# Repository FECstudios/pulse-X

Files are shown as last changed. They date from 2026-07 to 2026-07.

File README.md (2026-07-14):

# Pulse-X: Crowd Cheering Tool

Pulse-X is a portable battery powered cylindrical speaker engineered for high-noise outdoor environments, such as sports stadiums and open-air events. Works with wifi, bluetooth or locally with a sd card. Made this project to be used in VEX and FIRST competitions.

## Renders
Pulse-X Hardware View

## Hardware Schematics
circuit_image (6)

## Images


Demo Video: https://www.youtube.com/shorts/XgMtZgEX2DE
---
# Technical Overview

Pulse-X is powered by an ESP32-S3-WROOM-1. The ESP32 handles the web interface, audio streaming, and the OLED display at the same time. Audio is sent over I2S to a PCM5102A DAC OR with VHM-314, which provides much better sound quality than the built-in DAC found on many microcontrollers.

## Features

- Joins a public wifi, allowing devices to connect to it with BubbleUPnP or MediaMonkey
- Uses a PCM5102A I2S DAC for clean digital audio output.
- Uses a VHM-314 instead of built in bluetooth for smoother audio.
- 128×64 OLED display showing the current mode, volume level, playback status, and scrolling track names.
- Six physical buttons for volume control, play/pause, previous track, next track, and mode switching.
- Powered by a 3-cell Li-ion battery pack with a 3S BMS for battery protection and a buck converter to provide power to the components.
- Bluetooth, wi-fi AND sd card connectivity.
- On/Off and connection sounds
- Bluetooth module can be integrated as shown in schematics but its optional

---

# Hardware Connections

## Main Components

- ESP32-S3 N16R8 Development Board
- 1.3" SSD1306 OLED Display (I2C)
- PCM5102A I2S DAC Audio Decoder Module
- PAM8610 Stereo Audio Amplifier
- VHM-314 Bluetooth 5.0 Audio Receiver Module
- Micro SD Card Reader Module
- 2 × 4 Ω 5 W Speakers (66 × 66 mm)
- 7 × 6 × 6 mm Tactile Push Buttons (4.3 mm Height)
- MP1584 3A Step-Down (Buck) Voltage Regulator
- 3 × LG HG2 3000 mAh 3.7 V 20A 18650 Li-ion Batteries
- 3S 20A Battery Management System (BMS)
- 3S Li-ion/LiPo 12.6 V 2A Charging Module
- KCD1-101 3-Pin Mini Power Switch
- VHM-314 Bluetooth module   // OPTIONAL

| NAME | QUANTITY | PRICE PER UNIT (TL) | TOTAL (TL) | SELLER | SHIPPING (TL) | LINK |
|---|---:|---:|---:|---|---:|---|
| LG HG2 3000 mAh 3.7V 20A 18650 Li-ion Battery | 3 | 299.00 | 897.00 | Trendyol | 59.99 | https://www.trendyol.com/lg/hg2-3000-mah-3-7-v-20a-18650-li-ion-sarj-edilebilir-pil-p-142219925 |
| 1.3" SSD1306 OLED Screen | 1 | 227.31 | 227.31 | Direnç.net | 144.00 | https://www.direnc.net/13-inc-4-pin-oled-ekran-modulu-ssd1306-i2c-beyaz |
| ESP32-S3 N16R8 | 1 | 568.26 | 568.26 | Direnç.net | 0.00 | ESP32 S3 N16R8 WiFi Bluetooth Board |
| 6x6 4.3mm Tact Button | 7 | 1.48 | 10.36 | Direnç.net | 0.00 | https://www.direnc.net/6x6-42mm-tach-buton-4-bacak-en |
| Speaker 4Ω 5W 66×66mm | 2 | 86.40 | 172.80 | Motorobit | 137.00 | http://motorobit.com/hoparlor-4-ohm-4%CE%A9-5w-66x66mm |
| MP1584 Step-Down Voltage Regulator 3A | 1 | 50.22 | 50.22 | Robo90 | 0.00 | https://www.robo90.com/mp1584-dusurucu-voltaj-regulatoru-buck-3a |
| Micro SD Card Reader | 1 | 30.69 | 30.69 | Robo90 | 0.00 | https://www.robo90.com/micro-sd-kart-okuyucu-modulu-arduino-uyumlu |
| PAM8610 Sound Booster | 1 | 83.70 | 83.70 | Robo90 | 0.00 | https://www.robo90.com/pam8610-mini-dijital-ses-yukseltici |
| PCM5102A I2S DAC Audio Decoder Module | 1 | 50.22 | 50.22 | Robo90 | 0.00 | https://www.robo90.com/pcm5102a-i2s-dac-dekoder-modul |
| 3S 20A BMS | 1 | 50.40 | 50.40 | Robolink Market | 0.00 | https://www.robolinkmarket.com/3s-20a-bms-batarya-yonetim-ve-koruma-modulu |
| 3S Li-ion and LiPo Battery Charging Module 12.6V 2A | 1 | 52.20 | 52.20 | Robolink Market | 0.00 | https://www.robolinkmarket.com/3s-lion-ve-lipo-sarj-modulu |
| KCD1-101 3-Pin Mini | 1 | 5.18 | 5.18 | Motorobit | 0.00 | https://www.motorobit.com/kcd11-3-pin-mini-on-off-anahtar-siyah |
| VHM-314 | 1 | 111.60 | 111.60 | Robo90 | 0.00 | https://www.robo90.com/bluetooth-50-mikrofonlu-mp3-stereo-muzik-modulu-ses-alicisi |
| **Components Total** |  |  | **2,310.94 TL** |  |  |  |
| **Shipping Total** |  |  | **340.99 TL** |  |  |  |
| **Grand Total** |  |  | **2,651.93 TL** |  |  |  |

---

# Software

Pulse-X can be programmed using either the Arduino IDE or ESP-IDF.
Preprogrammed versions are available at firmware/bluetooth.ino firmware/onlySD.ino firmware/wifinsd.ino 

---

# Steps To Replicate

1. 3d print all of the files given at folder 3dprintfiles with your preferred slicer.
2. Solder and connect all of the components as shown in schematics
3. Flash the firmware to the esp32
4. Charge the batteries
5. Download your sound effects and preferred musics to the sd card
6. Connect all of the 3d printed pieces together
7. Connect to the device

# AI usage
AI was used to help write the firmware for this project. AI was partly used in part selection and troubleshooting.

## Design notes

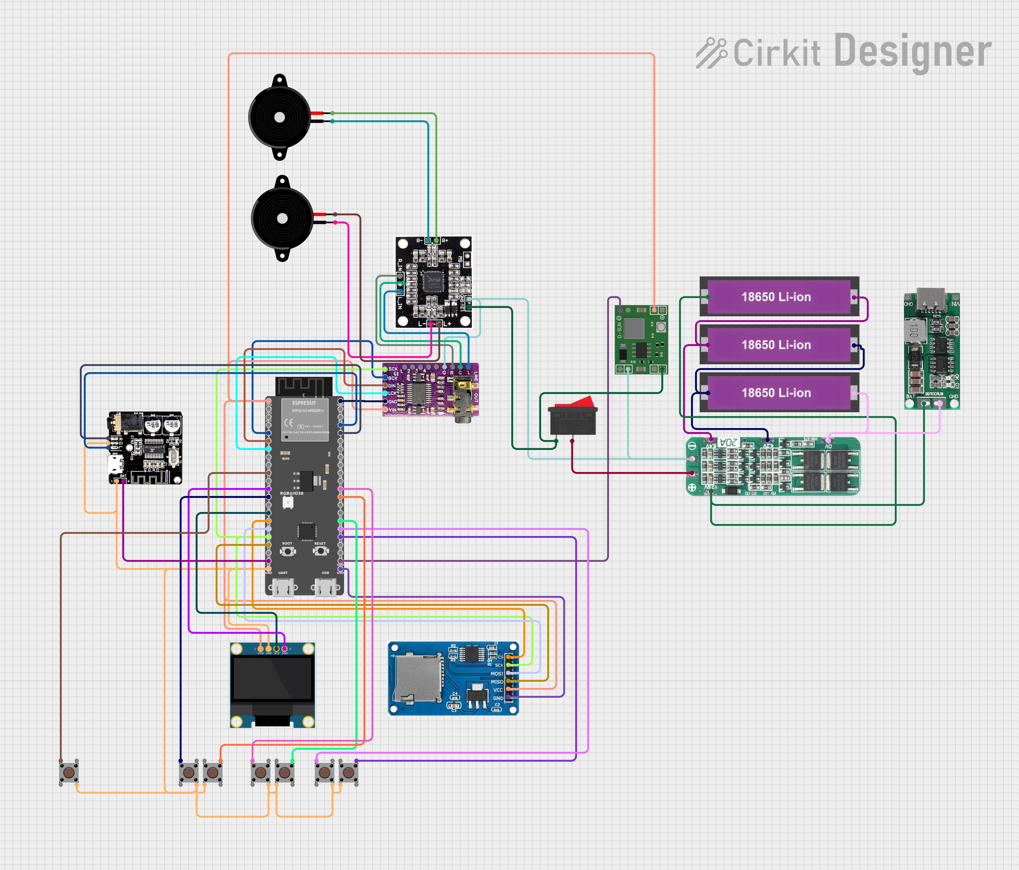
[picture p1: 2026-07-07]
circuitimage.png

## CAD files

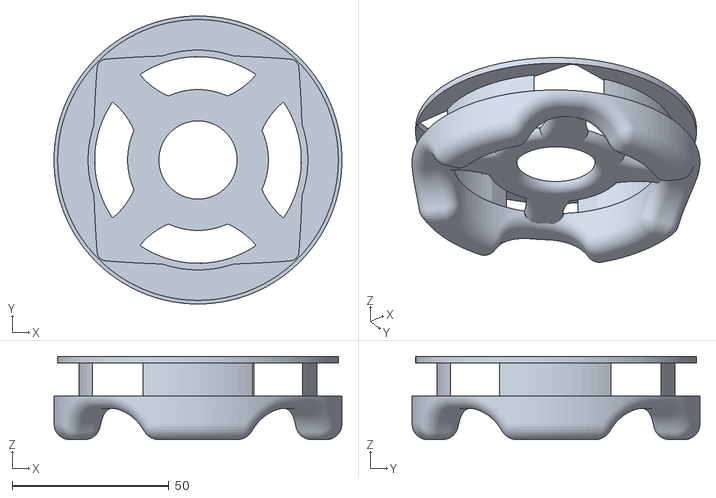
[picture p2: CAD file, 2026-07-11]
3dprintfiles/BOTTOM.stl
92.0 x 92.0 x 26.6

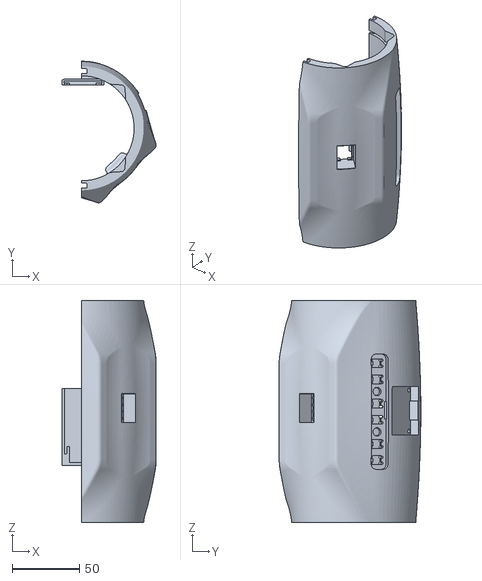
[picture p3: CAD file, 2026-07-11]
3dprintfiles/right.stl
70.2 x 105.3 x 165.0

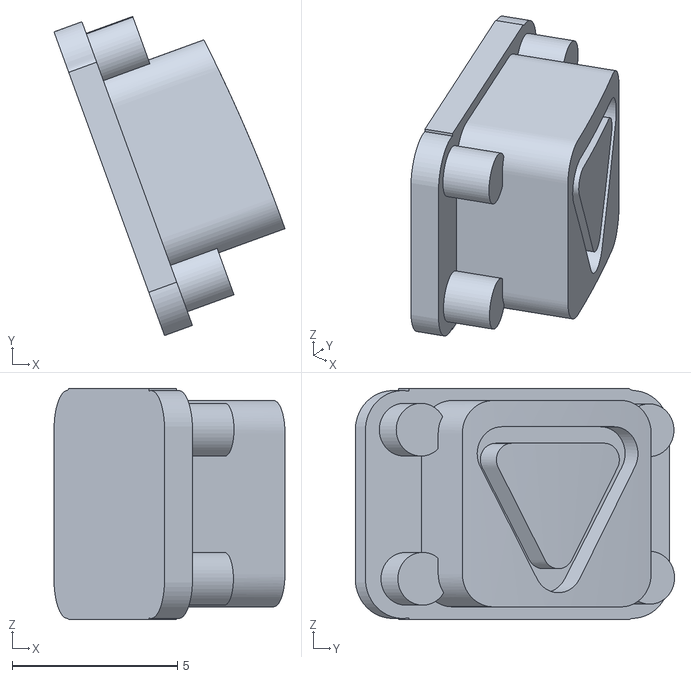
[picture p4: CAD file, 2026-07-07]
3dprintfiles/button4.stl
7.00 x 9.67 x 7.01

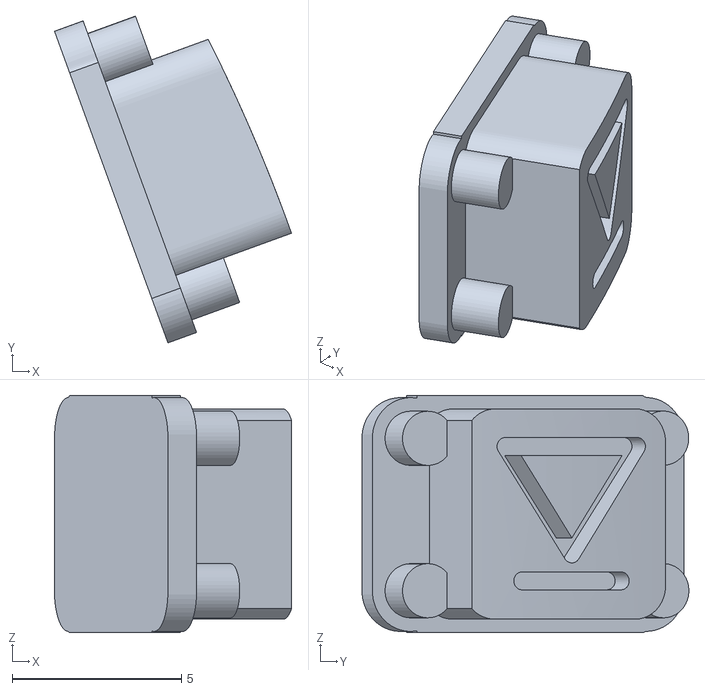
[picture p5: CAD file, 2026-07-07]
3dprintfiles/button1.stl
7.00 x 9.65 x 7.01

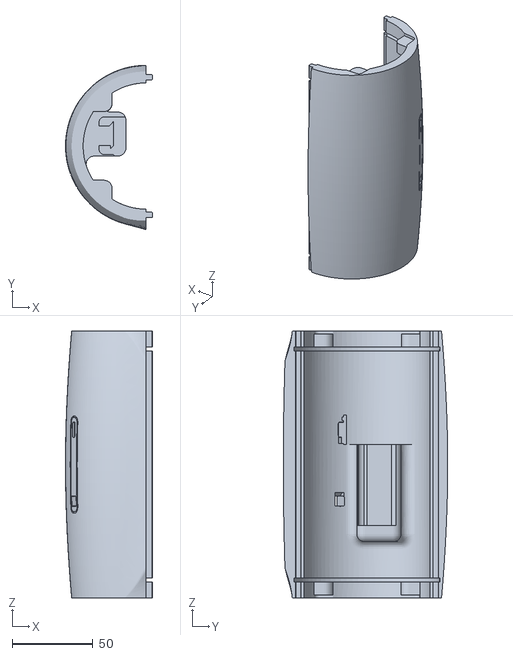
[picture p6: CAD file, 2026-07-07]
3dprintfiles/left.stl
53.8 x 101.6 x 165.0

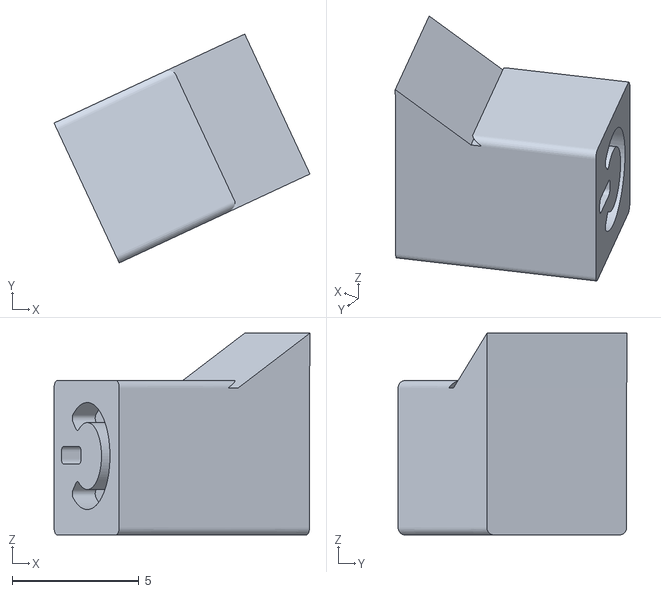
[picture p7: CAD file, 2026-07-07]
3dprintfiles/ONOFF.stl
10.1 x 9.04 x 7.98

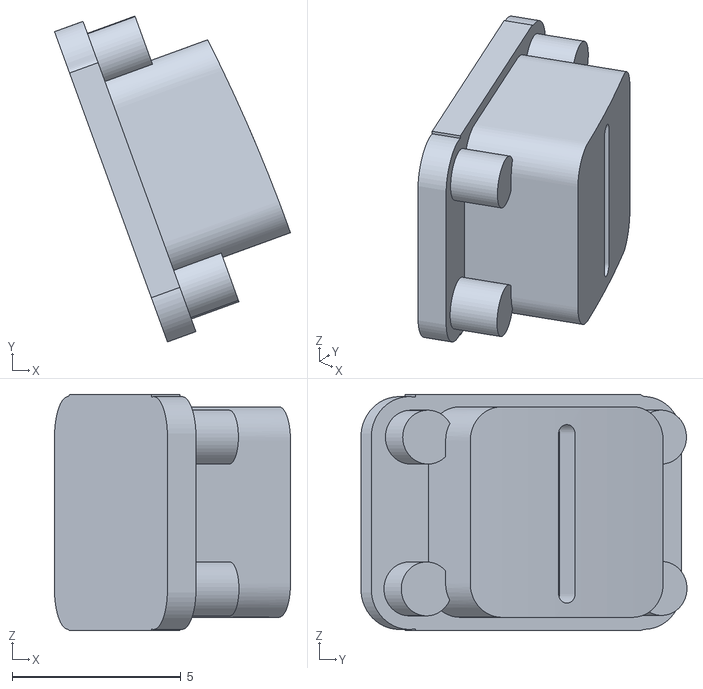
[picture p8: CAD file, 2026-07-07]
3dprintfiles/button6.stl
7.00 x 9.66 x 7.01

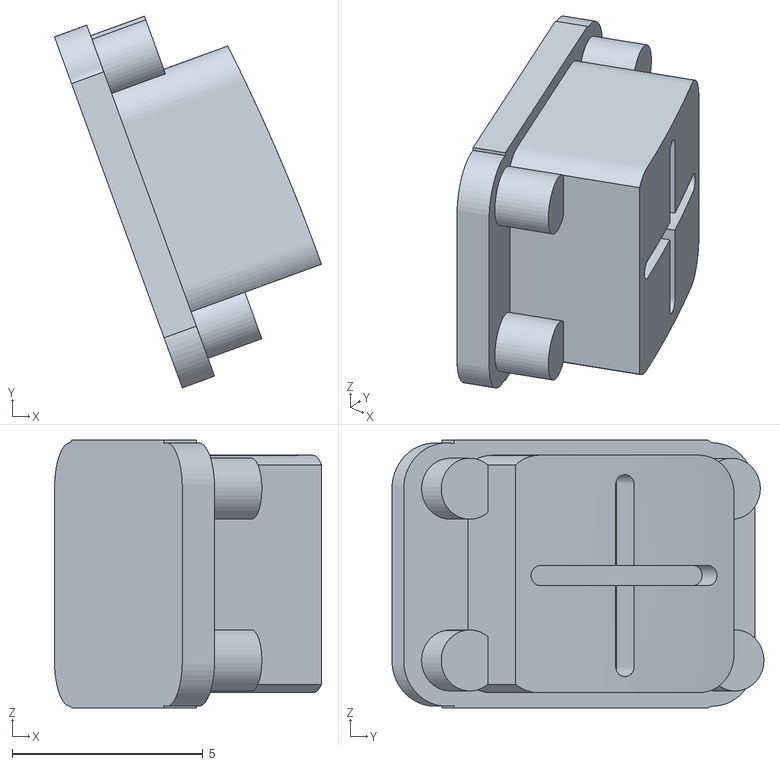
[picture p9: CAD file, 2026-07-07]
3dprintfiles/button5.stl
7.00 x 9.74 x 7.01

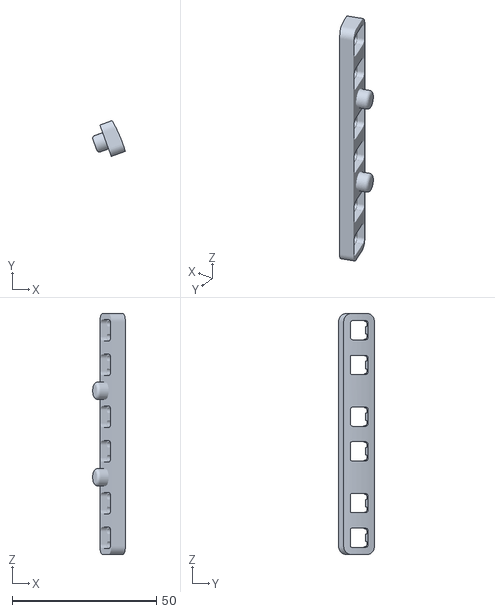
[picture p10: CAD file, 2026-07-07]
3dprintfiles/butonholders.stl
11.4 x 12.4 x 83.6

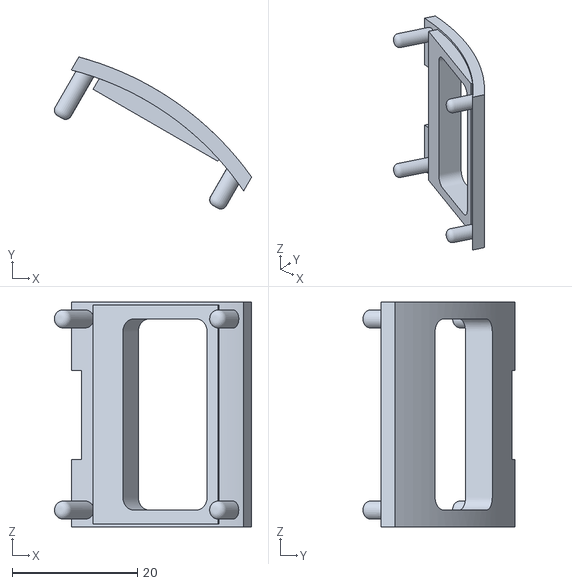
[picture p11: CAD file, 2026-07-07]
3dprintfiles/screencover.stl
31.5 x 24.3 x 35.9

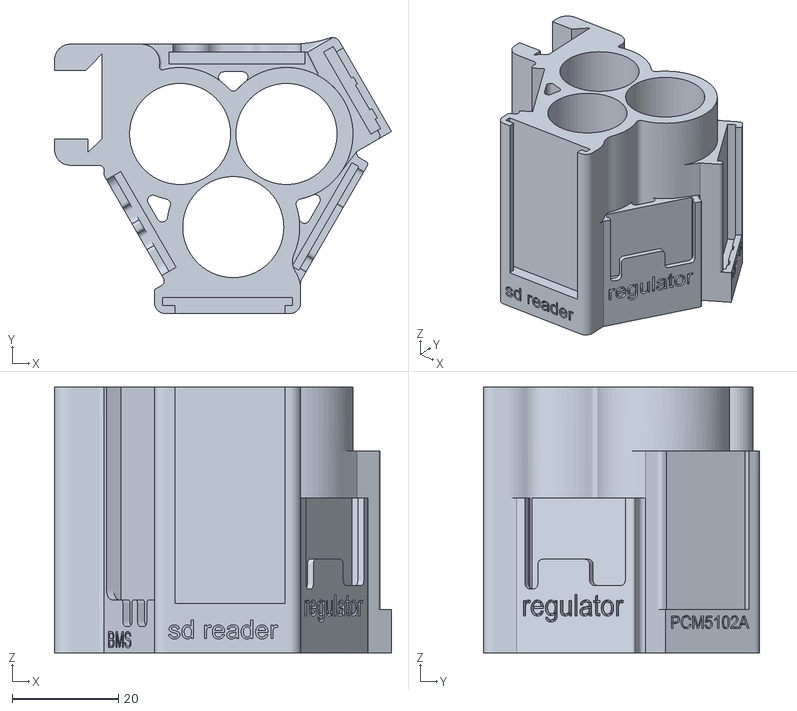
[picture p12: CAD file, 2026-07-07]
3dprintfiles/batteryholders.stl
63.3 x 51.9 x 50.0

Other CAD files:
3dprintfiles/top (4).stl
3dprintfiles/button2.stl
3dprintfiles/button3.stl

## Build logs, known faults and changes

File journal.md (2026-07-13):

title: PULSE-X
author: Kuzey (@craftfec) and Derin (@D_R1N)
description: Pulse-X is a portable battery powered cylindrical speaker engineered for high-noise outdoor environments, such as sports stadiums and open-air events.
created_at: "2026-06-26"

# June 26th: Started the project!
Author: craftfec

Today we started a new project it will be a bluetooth and wifi speaker made to cheer up the crowd at robotics matches at least that is what we want to build. We started with making a parts list and started making the cad files



**Total time spent: 2h 2m**
Recordings:
https://lapse.hackclub.com/timelapse/x79JwHw80_DK
https://lapse.hackclub.com/timelapse/8_gKt_B3zJ5e

# June 26th: Started the project!
Author: D_R1N

On our new project i started to select the parts we will use and worked on the schematics using the circit designer tool



**Total time spent: 2h 12m 26s**
Recordings:
https://lapse.hackclub.com/timelapse/CJvV61tmcs52
https://lapse.hackclub.com/timelapse/yrJAcUiZQl9d

# June 28th: Started CAD designing on fusion
Author: craftfec

Today i started the cad design by firstly designing the battery holders and also added slots for 3 more components with the batteries to reduce the ammount of wires used inside the build. Also tried to get a good cad model for the specific speakers we ordered but unfortunately had no luck



**Total time spent: 2h 16m 5s**
Recordings:
https://lapse.hackclub.com/timelapse/_Vc3Hfp5rxpG

# June 29th: More cad designed and parts ordered
Author: craftfec

Today i continued with the battery holder design, added slots for 2 more components and made the design look aesthetically pleasing. Also ordered the parts left after my friend bought the first half



**Total time spent: 1h**
Recordings:
https://lapse.hackclub.com/timelapse/xlZ42-g_Gx9J

# July 2nd: Finished the battery holders and started working on the case
Author: craftfec

Today we met up at my friends house, added sd card reader and printed the battery holders after that i started working on the outside of the speaker adding spikes on left and right sides for placing the device at 90 degrees and added feet for sideways placement



**Total time spent: 4h 2m**
Recordings:
https://lapse.hackclub.com/timelapse/tpy7AgIwUa08

# July 2nd: Printing the battery holders and soldering the batteries
Author: D_R1N

Today we met up at my house and printed the battery holders, after that i started to solder the batteries but couldnt without proffesional help. After trying for a while i gave up thinking the batteries could have been damaged from the heat.



**Total time spent: 2h 47m 14s**
Recordings:
https://lapse.hackclub.com/timelapse/5dx7Ywu7mEY0

# July 3rd: Trip to the factories
Author: D_R1N

Today we went on a trip to get the batteries professionaly made. After we got them done i continued with the soldering finishing up the bms, regulator and the charger. After that we could succesfully charge the 18650 batteries



**Total time spent: 3h 04m 48s**
Recordings:
https://lapse.hackclub.com/timelapse/M9-L9wLn_zZr

# July 3rd: On Off buttons
Author: craftfec

After coming back from our trip we realized that we need to add some sort of phsical switch to cut the electric or else the esp32 and the speaker would be constantly active and draining our batteries so i added a on off switch and hit in on the bottom of the model
Esp32 deep sleep mode button design:


**Total time spent: 1h 56m 41s**
Recordings:
https://lapse.hackclub.com/timelapse/lTfWhkKVHinp

# July 4th: Media control button designs
Author: craftfec

Today i added the button holders and all the buttons in a innovative style so that the buttons dont fall out or dont fall inside the case




**Total time spent: 2h 53m 1s**
Recordings:
https://lapse.hackclub.com/timelapse/X4p78sh8nN9x

# July 4th: SVG, sound effects and more solder
Author: D_R1N

Today i tried to find some good svg designs, audio effects to send to my friend who is doing the cad design. Also worked on some ui code on the oled screen. In the afternoon i acquired the parts from my friend and started working on the solder




**Total time spent: 2h 42m 23s**
Recordings:
https://lapse.hackclub.com/timelapse/QX8U-kUTgIU8
https://lapse.hackclub.com/timelapse/zpm87LCeGYsF
https://lapse.hackclub.com/timelapse/9LhlHynIek39

# July 5th: Fixing my mistakes with the solder
Author: D_R1N

Today i learned the sad news that we needed to connect the batteries better with the BMS so i worked on doing that and also fixed the regulator connections


**Total time spent: 1h 26m**
Recordings:
https://lapse.hackclub.com/timelapse/i443_Us5i-Yl

# July 5th: Speaker protector and schematics
Author: craftfec

Today i added a speaker protector to our top and bottom parts and sent the models to print to my friend Derin and started working on the schematics on circitdesigner




**Total time spent: 2h 5m**
Recordings:
https://lapse.hackclub.com/timelapse/fUiaW7e-g2Ig
https://lapse.hackclub.com/timelapse/-oq5R-IBSlbL

# July 6th: BLE issues
Author: craftfec

Today i finished up the schematics design and realized the bluetooth on the esp32 s3 does not have regular bluetooth but only has Bluetooth low energy so we added a new component VHM-314 to our schematics and to our bom.
Also wrote all of the journals we were dreading to write.




**Total time spent: 3h**
Recordings:
https://lapse.hackclub.com/timelapse/h-_9Gzua42wM
https://lapse.hackclub.com/timelapse/YINomfWPwFnc

# July 6th: Right side of the case
Author: D_R1N

Today i printed the right side of the case design and continued my work on the left side integrating the buttons, the on off switch the screen and more



**Total time spent: 2h 51m 9s**
Recordings:
https://lapse.hackclub.com/timelapse/utEOT1DLX6nZ

# July 7th: Issues with the Esp32 S3
Author: D_R1N

Today i had some issues with flashing the test firmwares to the esp32 s3 since i couldnt meet up with kuzey because of the NATO Ankara Summit i decided to use my cheap and probably cloned esp32D and still could not get the oled display to work with both of my esp32's :(




**Total time spent: 4h 35m 01s**
Recordings:
https://lapse.hackclub.com/timelapse/nuqc9frhJh3B

# July 7th: Issues with the Esp32 S3 and firmware
Author: craftfec

Today i countinued my day by writing the firmware but recieved the sad news that my friend couldnt flash anything on the chip i previously tested and managed to work then continued by trying to help him but achieved no success with the esp32 s3 AND the oled screen hopefully we will meet sometime and get those fixed


**Total time spent: 6h 20s**
Recordings:
https://lapse.hackclub.com/timelapse/LaqP55hy5ArD
https://lapse.hackclub.com/timelapse/Q2pDoU28dboI

# July 8th: Issues with speakers
Author: D_R1N

Today i countinued with soldering of the speakers but i couldnt get them to work with my Esp32D in the end the chip started overheating


**Total time spent: 2h 16m**
Recordings:
https://lapse.hackclub.com/timelapse/n-Ss9dm3OcC4

# July 9th: The big meetup and solder
Author: D_R1N

Today we finally met up in my friends place and he finally got his hands on the project. We started the work with getting the esp32d out since it was short circuting. Then we fixed the oled screen and soldered all of the pieces together


**Total time spent: 1h 59m 1s**
Recordings:
https://lapse.hackclub.com/timelapse/Yu9Xosdbv95M

# July 9th: The big meetup and code
Author: craftfec

Today we finally met up in my place and i finally got my hands on the project. After finishing up all of the wiring we had some issues with the code since i was uploading the code but the device did not recieve it or kept rebooting at the end the issue was fixed by increasing the mb and fixing psram settings from the arduino ide



**Total time spent: 4h**
Recordings:
https://lapse.hackclub.com/timelapse/Iv2Pfilxi044

# July 11th: The 2nd big meetup and wifi connectivity
Author: craftfec

Today we met up again and worked a lot on getting the wifi functionality with UPNP and i fixed the cad models of the parts that showed issues in the model


**Total time spent: 5h 32m 10s**
Recordings:
https://lapse.hackclub.com/timelapse/v2fOV9HvRw3P

# July 12th: The end.
Author: craftfec

Today was a beautiful morning since we succesfully finished the demo of the project and filmed the demo video, uploaded the finally done code to github. Downloaded some of the offline songs we wanted.



**Total time spent: 2h 30m 2s**
Recordings:
https://lapse.hackclub.com/timelapse/Yv39VQiENtMH

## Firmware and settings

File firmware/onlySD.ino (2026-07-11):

#include <Wire.h>
#include <Adafruit_GFX.h>
#include <Adafruit_SSD1306.h>
#include <SPI.h>
#include <SD.h>
#include <Audio.h>

// Pin Definitions
#define SDA_PIN     8
#define SCL_PIN     9
#define SD_CS       10
#define SPI_MOSI    11
#define SPI_SCK     12
#define SPI_MISO    13
#define I2S_BCLK    5
#define I2S_LRC     7
#define I2S_DOUT    6
#define BTN_VOL_UP  3
#define BTN_VOL_DN  41
#define BTN_PLAY    40
#define BTN_PREV    47
#define BTN_NEXT    21

// Display Configurations
#define SCREEN_WIDTH  128
#define SCREEN_HEIGHT 64
#define OLED_RESET    -1
#define I2C_ADDRESS   0x3C

// Audio Configurations
#define MAX_TRACKS    100
#define MAX_VOLUME    21
#define DEBOUNCE_MS   250
#define SCROLL_MS     40

// Global Objects
Adafruit_SSD1306 display(SCREEN_WIDTH, SCREEN_HEIGHT, &Wire, OLED_RESET);
Audio audio;

// System States
String playlist[MAX_TRACKS];
int totalTracks = 0;
int currentTrackIndex = 0;
bool isPlaying = true;
bool pendingEof = false;
bool startupPlayed = false;
bool sysSoundPlaying = false;
int volumePercent = 10;
unsigned long lastBtnTime = 0;

// Scrolling Text Variables
int scrollX = SCREEN_WIDTH;
unsigned long lastScrollTime = 0;
String scrollName = "";

/**
 * Checks if the given file name belongs to system notification sounds.
 */
bool isSysFile(const char* name) {
  return (strcmp(name, "0001.mp3") == 0 || strcmp(name, "0002.mp3") == 0 ||
          strcmp(name, "0003.mp3") == 0 || strcmp(name, "0004.mp3") == 0);
}

/**
 * Scans the root directory for valid MP3 files and populates the playlist.
 */
void scanFolder(File dir) {
  while (true) {
    File entry = dir.openNextFile();
    if (!entry) break;

    if (!entry.isDirectory()) {
      const char* name = entry.name();
      String lowName = String(name);
      lowName.toLowerCase();

      if (lowName.endsWith(".mp3") && !isSysFile(name) && totalTracks < MAX_TRACKS) {
        playlist[totalTracks++] = "/" + String(name);
      }
    }
    entry.close();
  }
}

/**
 * Resets the scrolling properties for the currently active track.
 */
void resetScroll() {
  scrollX = 20; // Set to 20 for immediate visibility on screen
  if (totalTracks > 0) {
    scrollName = playlist[currentTrackIndex];
    scrollName.replace("/", "");
    if (scrollName.endsWith(".mp3") || scrollName.endsWith(".MP3")) {
      scrollName = scrollName.substring(0, scrollName.length() - 4);
    }
  }
}

/**
 * Updates and renders the main playback status interface.
 */
void showStatus() {
  display.clearDisplay();
  display.drawRoundRect(0, 0, SCREEN_WIDTH, SCREEN_HEIGHT, 5, SSD1306_WHITE);
  display.drawFastHLine(2, 13, 124, SSD1306_WHITE);
  display.drawFastHLine(2, 50, 124, SSD1306_WHITE);
  display.setTextSize(1);
  display.setTextColor(SSD1306_WHITE);

  // Header Info
  display.setCursor(5, 3);
  display.print("PULSE-X");
  display.setCursor(88, 3);
  display.print(currentTrackIndex + 1);
  display.print("/");
  display.print(totalTracks);

  // Playback Icon State
  display.setCursor(5, 16);
  if (isPlaying) {
    display.print((char)16); // Play icon
  } else {
    display.print("||");       // Pause icon
  }

  // Scrolling Track Name
  display.setCursor(scrollX, 28);
  display.print(scrollName);

  // Volume Info & Bar
  int volPct = map(volumePercent, 0, MAX_VOLUME, 0, 100);
  display.setCursor(5, 54);
  display.print("VOL ");
  display.print(volPct);
  display.print("%");

  int barW = map(volumePercent, 0, MAX_VOLUME, 0, 60);
  display.drawRect(62, 53, 62, 8, SSD1306_WHITE);
  display.fillRect(63, 54, barW, 6, SSD1306_WHITE);

  display.display();
}

/**
 * Displays a generic info or system message on screen.
 */
void showMsg(const char* msg) {
  display.clearDisplay();
  display.drawRoundRect(0, 0, SCREEN_WIDTH, SCREEN_HEIGHT, 5, SSD1306_WHITE);
  display.setTextSize(1); 
  display.setTextColor(SSD1306_WHITE);
  display.setCursor(5, 4); 
  display.print("PULSE-X");
  display.drawFastHLine(2, 14, 124, SSD1306_WHITE);
  display.setCursor(5, 22); 
  display.print(msg);
  display.display();
}

/**
 * Connects and starts playing the track at the specified index.
 */
void playTrack(int index) {
  if (totalTracks == 0) return;
  audio.connecttoFS(SD, playlist[index].c_str());
  isPlaying = true;
  resetScroll();
  showStatus();
}

/**
 * Plays a system sound effect without updating track data.
 */
void playSys(const char* path) {
  if (SD.exists(path)) { 
    audio.connecttoFS(SD, path); 
    sysSoundPlaying = true; 
  }
}

/**
 * Handles text scrolling animation for long track titles.
 */
void updateScroll() {
  if (!isPlaying) return;
  if (millis() - lastScrollTime < SCROLL_MS) return;
  
  lastScrollTime = millis();
  int textW = scrollName.length() * 6; // Approx width in standard text size
  scrollX -= 2;
  
  if (scrollX < -(textW)) {
    scrollX = SCREEN_WIDTH;
  }
  showStatus();
}

/**
 * Non-blocking button handler with software debounce.
 */
void checkButtons() {
  if (millis() - lastBtnTime < DEBOUNCE_MS) return;
  
  static bool upL = HIGH, dnL = HIGH, plL = HIGH, prL = HIGH, nxL = HIGH;
  bool changed = false;

  // Volume Up
  bool up = digitalRead(BTN_VOL_UP);
  if (up == LOW && upL == HIGH) {
    volumePercent = min(MAX_VOLUME, volumePercent + 1);
    audio.setVolume(volumePercent);
    if (!sysSoundPlaying) playSys("/0003.mp3");
    showStatus(); 
    changed = true;
  } 
  upL = up;

  // Volume Down
  bool dn = digitalRead(BTN_VOL_DN);
  if (dn == LOW && dnL == HIGH) {
    volumePercent = max(0, volumePercent - 1);
    audio.setVolume(volumePercent);
    if (!sysSoundPlaying) playSys("/0004.mp3");
    showStatus(); 
    changed = true;
  } 
  dnL = dn;

  // Play / Pause
  bool pl = digitalRead(BTN_PLAY);
  if (pl == LOW && plL == HIGH) {
    audio.pauseResume(); 
    isPlaying = !isPlaying;
    showStatus(); 
    changed = true;
  } 
  plL = pl;

  // Prevent divide by zero if playlist is empty for track hopping
  if (totalTracks > 0) {
    // Previous Track
    bool pr = digitalRead(BTN_PREV);
    if (pr == LOW && prL == HIGH) {
      currentTrackIndex = (currentTrackIndex - 1 + totalTracks) % totalTracks;
      playTrack(currentTrackIndex); 
      changed = true;
    } 
    prL = pr;

    // Next Track
    bool nx = digitalRead(BTN_NEXT);
    if (nx == LOW && nxL == HIGH) {
      currentTrackIndex = (currentTrackIndex + 1) % totalTracks;
      playTrack(currentTrackIndex); 
      changed = true;
    } 
    nxL = nx;
  }

  if (changed) {
    lastBtnTime = millis();
  }
}

void setup() {
  Serial.begin(115200);
  delay(500);
  
  // Initialize Buttons
  pinMode(BTN_VOL_UP, INPUT_PULLUP); 
  pinMode(BTN_VOL_DN, INPUT_PULLUP);
  pinMode(BTN_PLAY,   INPUT_PULLUP);   
  pinMode(BTN_PREV,   INPUT_PULLUP);
  pinMode(BTN_NEXT,   INPUT_PULLUP);

  // Initialize I2C Display
  Wire.begin(SDA_PIN, SCL_PIN);
  Wire.setClock(400000);
  if (!display.begin(SSD1306_SWITCHCAPVCC, I2C_ADDRESS)) {
    while (1); // Halt if OLED fails
  }
  display.setTextWrap(false);
  display.setRotation(2);
  showMsg("Initializing SD...");

  // Initialize SPI & SD Card
  SPI.begin(SPI_SCK, SPI_MISO, SPI_MOSI, SD_CS);
  delay(100);
  if (!SD.begin(SD_CS, SPI)) { 
    showMsg("NO SD CARD!"); 
    while (1); 
  }

  // Parse Audio Tracks
  File root = SD.open("/");
  scanFolder(root); 
  root.close();
  
  Serial.print("Tracks discovered: "); 
  Serial.println(totalTracks);
  
  if (totalTracks == 0) { 
    showMsg("No MP3 found!"); 
    while (1); 
  }

  // Audio Setup
  audio.setPinout(I2S_BCLK, I2S_LRC, I2S_DOUT);
  audio.setVolume(volumePercent);

  resetScroll();
  showMsg("Welcome!");
  playSys("/0001.mp3");
}

void loop() {
  audio.loop();
  checkButtons();
  
  if (pendingEof) { 
    pendingEof = false; 
    playTrack(currentTrackIndex); 
  }
  
  if (startupPlayed && !sysSoundPlaying) {
    updateScroll();
  }
}

// Audio Library Callbacks
void audio_info(const char* info) { 
  Serial.println(info); 
}

void audio_eof_mp3(const char* info) {
  if (!startupPlayed) { 
    startupPlayed = true; 
    sysSoundPlaying = false; 
    playTrack(0); 
    return; 
  }
  if (sysSoundPlaying) { 
    sysSoundPlaying = false; 
    pendingEof = true; 
    return; 
  }
  
  currentTrackIndex = (currentTrackIndex + 1) % totalTracks;
  pendingEof = true;
}

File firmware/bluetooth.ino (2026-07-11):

#include <Wire.h>
#include <Adafruit_GFX.h>
#include <Adafruit_SSD1306.h>
#include <SPI.h>
#include <SD.h>
#include <Audio.h>

// --- OLED ---
#define SCREEN_WIDTH 128
#define SCREEN_HEIGHT 64
#define SDA_PIN 8
#define SCL_PIN 9
Adafruit_SSD1306 display(SCREEN_WIDTH, SCREEN_HEIGHT, &Wire, -1);

// --- SD ---
#define SD_CS    10
#define SPI_MOSI 11
#define SPI_SCK  12
#define SPI_MISO 13

// --- I2S ---
#define I2S_BCLK 5
#define I2S_LRC  7
#define I2S_DOUT 6

// --- Butonlar ---
#define BTN_VOL_UP 3
#define BTN_VOL_DN 41
#define BTN_PLAY   40
#define BTN_PREV   47
#define BTN_NEXT   21

// --- VHM-314 kontrol pinleri ---
// VHM-314'ün KEY pinine bağla — LOW = play/pause, pulse = next/prev
#define VHM_PLAY_PIN 15
#define VHM_NEXT_PIN 16
#define VHM_PREV_PIN 17

Audio audio;

// Sistem dosyaları — playlist'e alınmayacak
const String SYS_FILES[] = {"/0001.mp3", "/0002.mp3", "/0003.mp3", "/0004.mp3"};
#define SYS_FILE_COUNT 4

#define MAX_TRACKS 100
String playlist[MAX_TRACKS];
int totalTracks = 0;
int currentTrackIndex = 0;

bool isPlaying = true;
int volumePercent = 14;
bool btMode = false;       // false = SD, true = BT (VHM-314)
bool pendingEof = false;

unsigned long lastBtnTime = 0;
const int debounce = 250;

// --- VHM-314 sinyal gönder ---
void vhmPulse(int pin, int ms = 200) {
  digitalWrite(pin, LOW);
  delay(ms);
  digitalWrite(pin, HIGH);
}

bool isSysFile(const String& path) {
  for (int i = 0; i < SYS_FILE_COUNT; i++) {
    if (path.equalsIgnoreCase(SYS_FILES[i])) return true;
  }
  return false;
}

void scanFolder(File dir) {
  while (true) {
    File entry = dir.openNextFile();
    if (!entry) break;
    if (!entry.isDirectory()) {
      String name = "/" + String(entry.name());
      String nameLow = name;
      nameLow.toLowerCase();
      if (nameLow.endsWith(".mp3") && !isSysFile(nameLow) && totalTracks < MAX_TRACKS) {
        playlist[totalTracks++] = name;
      }
    }
    entry.close();
  }
}

// --- Startup sesi çal, bitince asıl parçayı başlat ---
bool startupPlayed = false;

void playSysSound(const char* path) {
  if (SD.exists(path)) {
    audio.connecttoFS(SD, path);
  }
}

// --- OLED ---
void showStatus() {
  display.clearDisplay();
  display.drawRoundRect(0, 0, 128, 64, 6, SSD1306_WHITE);
  display.drawFastHLine(2, 12, 124, SSD1306_WHITE);

  display.setTextSize(1);
  display.setTextColor(SSD1306_WHITE);
  display.setCursor(5, 2);
  display.print("PULSE-X");

  // Mod göstergesi
  display.setCursor(85, 2);
  if (btMode) {
    display.print("\xF0 BT"); // BT simgesi yerine "BT"
  } else {
    display.print("SD \x10");
  }

  // Durum
  display.setCursor(5, 16);
  if (btMode) {
    display.print("  BLUETOOTH MODE");
    display.setCursor(5, 30);
    display.print("   VHM-314 aktif");
    display.setCursor(5, 44);
    display.print("Telefon baglayabilirsin");
  } else {
    // Play/Pause
    display.setCursor(34, 16);
    if (isPlaying) {
      display.print("\x10 PLAYING");
    } else {
      display.print("|| PAUSED ");
    }

    // Dosya adı — uzunsa kırp
    String name = playlist[currentTrackIndex];
    name.replace("/", "");
    if (name.length() > 16) name = name.substring(0, 15) + "~";
    display.setCursor(5, 30);
    display.print(name);

    // Track no
    display.setCursor(5, 43);
    display.print(currentTrackIndex + 1);
    display.print("/");
    display.print(totalTracks);

    // Volume bar
    display.setCursor(50, 43);
    display.print("VOL:");
    display.drawRect(80, 42, 42, 8, SSD1306_WHITE);
    int bar = map(volumePercent, 0, 21, 0, 40);
    display.fillRect(81, 43, bar, 6, SSD1306_WHITE);
  }

  display.display();
}

void showBoot(const char* msg) {
  display.clearDisplay();
  display.drawRoundRect(0, 0, 128, 64, 6, SSD1306_WHITE);
  display.setCursor(5, 5);
  display.setTextSize(1);
  display.setTextColor(SSD1306_WHITE);
  display.print("PULSE-X");
  display.drawFastHLine(2, 14, 124, SSD1306_WHITE);
  display.setCursor(5, 20);
  display.print(msg);
  display.display();
}

void playTrack(int index) {
  audio.connecttoFS(SD, playlist[index].c_str());
  isPlaying = true;
  showStatus();
}

void checkButtons() {
  if (millis() - lastBtnTime < debounce) return;

  static bool upL=HIGH, dnL=HIGH, plL=HIGH, prL=HIGH, nxL=HIGH;
  bool changed = false;

  bool up = digitalRead(BTN_VOL_UP);
  if (up == LOW && upL == HIGH) {
    volumePercent = min(21, volumePercent + 1);
    if (!btMode) {
      audio.setVolume(volumePercent);
      playSysSound("/0003.mp3"); // vol+ sesi
    }
    showStatus();
    changed = true;
  }
  upL = up;

  bool dn = digitalRead(BTN_VOL_DN);
  if (dn == LOW && dnL == HIGH) {
    volumePercent = max(0, volumePercent - 1);
    if (!btMode) {
      audio.setVolume(volumePercent);
      playSysSound("/0004.mp3"); // vol- sesi
    }
    showStatus();
    changed = true;
  }
  dnL = dn;

  bool pl = digitalRead(BTN_PLAY);
  if (pl == LOW && plL == HIGH) {
    if (btMode) {
      vhmPulse(VHM_PLAY_PIN); // VHM-314'e play/pause
    } else {
      audio.pauseResume();
      isPlaying = !isPlaying;
    }
    showStatus();
    changed = true;
  }
  plL = pl;

  bool pr = digitalRead(BTN_PREV);
  if (pr == LOW && prL == HIGH) {
    if (btMode) {
      vhmPulse(VHM_PREV_PIN);
    } else {
      currentTrackIndex = (currentTrackIndex - 1 + totalTracks) % totalTracks;
      playTrack(currentTrackIndex);
    }
    showStatus();
    changed = true;
  }
  prL = pr;

  bool nx = digitalRead(BTN_NEXT);
  if (nx == LOW && nxL == HIGH) {
    if (btMode) {
      vhmPulse(VHM_NEXT_PIN);
    } else {
      currentTrackIndex = (currentTrackIndex + 1) % totalTracks;
      playTrack(currentTrackIndex);
    }
    showStatus();
    changed = true;
  }
  nxL = nx;

  // PREV + NEXT aynı anda = mod değiştir
  if (pr == LOW && nx == LOW) {
    btMode = !btMode;
    if (btMode) {
      audio.stopSong();
    } else {
      audio.setPinout(I2S_BCLK, I2S_LRC, I2S_DOUT);
      audio.setVolume(volumePercent);
      playTrack(currentTrackIndex);
    }
    showStatus();
    delay(500);
    lastBtnTime = millis();
    return;
  }

  if (changed) lastBtnTime = millis();
}
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

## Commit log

2026-07-07 cad files
2026-07-11 Refactor Bluetooth firmware with new pin definitions
